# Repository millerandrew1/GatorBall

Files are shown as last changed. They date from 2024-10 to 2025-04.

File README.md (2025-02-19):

# GatorBall

# Sprint 1 10/8/2024 to 10/25/2024: Pre-Alpha Build
Work Completed: 
  This sprint we focuses on the front end of our design. We worked on showing dummy data and making the program that the referee will be using when determining the position of the football. We created a client that would act as our "football" and that would connect to a server and send dummy data which represents the distance from the anchor points. Then we have a python script called ble_triangulate.py that does the calculation of the exact position of the client and then we output that to our UI which displays the data. 

  We received our ESP-32 and DW3000 on Thursday the day before the Pre-Alpha was due so we did not have time to write a lot of code but we did have resources that we previously found and used that code to test our microchips. We were successfully able to send and receive data between the two chips and the data was the distance between the two microchips. In the future we will add the third DW3000 which will act as the football and it will take in the distance between the two microchips and then it will send that data to the ble_triangulate to calculate the position of the ball.

# Sprint 2 10/26/2024 to 11/22/2024: Prototype Design
This sprint we focued on getting the data from our tag to print to the UI. We tried to use another DW3000 to be the football but due to issues with Ardunio and there not being a compatible library we are sticking with the 1 anchor point and 1 tag for the prototype. The tag takes data from the anchor point through UWB and then is connected through bluetooth to our UI using a COM Port where we display the distance from the tag from the anchor point on the football field. We also have it continuously send data through the bluetooth so that every few miliseconds it gets new data and updates the UI. Also when the tag moves it is shown on the UI as a football moving on the field. 

Future plans for next sprint involve trying to incorporate a second anchor point so we can get a 2D position field instead of the 1D field we have now. We also need to make a PCB with the DW3000 and the ESP-32 along with including a power source. This will then need to be incorporated into a football. We also plan on transferring our python UI into a react application in order to make the project accessable for apps to be able to use it. Along with that we want to make our UI more interactable which will take in more inputs like line of scrimmage, first down line, and other various things involved in a football game (score, team names, clock time). We also have a football moving on the screen but we want to be able to visually show the line of scrimmage and the first down line.  

# Sprint 3 1/13/2025 to 1/30/2025: Alpha Build
This sprint we focused on several things in order to maximize our productivity. First we started working on the PCB that will go into the football and we are designing it on KiCad. We also ordered another anchor point to use as testing for our two anchor point postion triangulation. For our beta build if our PCB is not ready we want to use this extra anchor point as the football so we can start writing the code for it.  Next we updated our UI to be able to take in inputs and have the first down and line of scrimmage lines move depending on where the user wants the lines to be placed. We also are trying to use react to be able to host the program instead of python.

# Sprint 4 1/31/2025 to 2/21/2025: Beta Build
This sprint we continued to add features to the UI. We allowed the user to select which side of the field the line of scrimmage and first down markers were. We also made the lines scaled better and we created a formula to make the football move to scale as it would on a real field. We designed our PCB and ordered it and continued to wrok on the React application. We also designed and printed pylons for the anchor points. 

# PROCESS FOR RUNNING CODE AND CONNECTING BLUETOOTH TO PC

First go to src/hardware/range_rx and upload that Arduino code to one of the DW3000 ESP 32 modules. That is now the tag. Then in src/hardware/range_tx upload that to the other one and that is your anchor point. They should now be sending data to each other and the tag should be serial printing the distance. To connect the tag to the bluetooth go to bluetooth settings and scroll down and click devices then in there click more bluetooth settings. In there click the tab that says COM PORTS and click add and add the ESP_32. Take note of what COM Port it is connected to. Finally go to src/FrontEnd/ui.py. Change line 44 to reflect what COM port the bluetooth is transmitting through. Then, open PUTTY or any other application used to connect to serial ports. Connect to the COM port you recorded and use a baud rate of 115200. Ensure that you can see data coming in over the serial port terminal. If so, close the serial port terminal. You are now ready to run the application. Execute "python ui.py" and you should see data printing to the UI as well as the position of the ball changing on screen. To identofy we named the two anchor points the one with the short cord is 12.

# BUGS

Bluetooth and UWB, like many other wireless protocols, are finicky. Throughout our design process, we have encountered many situations where connecting to the ESP32 tag that we will be putting into a football over Bluetooth has been unreliable and difficult to get working at times. Furthermore, after testing the UWB capabilities of the DWM3000 modules, we’ve discovered that it is prone to interference from physical obstructions like walls and even people as the transmission of data is impeded by these effects. Our workaround to these issues for the purpose of the prototype has been to disconnect and reconnect to the Bluetooth device as well as maintaining “line of sight” for the two ESP32s communicating over UWB. Also, we check to ensure that the data we are receiving is of the valid format (i.e., a numerical float value). We have determined that at this time, so long as the proper preparations have been made, there is currently no need for any other error correction or recovery mechanisms for the prototype. However, in the future, we would like to implement an Automatic Repeat Request (ARQ) system for 1) the device communicating with the tag over Bluetooth and 2) the tags and anchors communicating over UWB. This will assist in ensuring that instances of data are received correctly by the relevant devices and provide us with more precision with the real-time location tracking of the football. 

# DEPENDENCIES

Bleak BLE - https://github.com/hbldh/bleak 
Localization - https://github.com/kamalshadi/Localization
Localization dependency (may not be needed) - https://shapely.readthedocs.io/en/stable/

Installation commands
pip install localization
pip install bleak
pip install shapely

# Effort Log
Please disregard the effort log in this repo because you cannot see the comments made. The link for our effort log is here at this link below:
https://docs.google.com/spreadsheets/d/1YpcHQpgFyinJQXn12217S25mA8S0SkYA/edit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

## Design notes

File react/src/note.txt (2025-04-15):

# WebSocket Imports
    @app.websocket("/ws")
    async def websocket_endpoint(websocket: WebSocket)
        await websocket.accept()
        data = {"time": curren_time, "yardX": current_ball_x, "yardY": current_ball_y}
        await websocket.send_json(data)
        await asyncio.sleep(1)

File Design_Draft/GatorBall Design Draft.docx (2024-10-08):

GatorBall Design Draft

Introduction - project value

- Purpose/Need - Describe the purpose in society for the project you are designing. Specifically, explain why it is needed, by whom, and in what context. Identify how the project is useful and goes beyond a mere demonstration.
  - This product is intended for football enthusiasts to accurately track first-downs without the need for a referee. It is needed because having a referee step out onto the field to manually measure the football and determine if a first-down has been established greatly slows down the momentum of the game and is also cumbersome to do. Our product will resolve this issue by providing an effortless way of tracking first-downs without the need for any human intervention. This product is primarily intended for small-scale football games like flag football or, potentially, intramural-level games.
- Augustus - Domain & Prior Art - Explain the field / area of the project and describe existing work in this area. Provide examples from existing commercial products, web searches, or articles appearing in the literature. All examples should be cited. Identify what features will differentiate your solution from others and why your project will make a difference.
  - Existing work similar to our product is used heavily in the NFL [1]. The NFL embeds RFID tags in player uniforms as well as the football itself. These RFID tags are extremely lightweight and unobtrusive, so they have a negligible impact on gameplay. The data collected by these tags allows the NFL to track statistics such as ball height, position, velocity, as well as player speed, passing rates and much more. These statistics greatly enhance the quality of the game and allow for the NFL as well as football enthusiasts at home to deep-dive into player stats. Our product, on the other hand, will focus specifically on the ball position to allow us to determine if a first-down has been made.
- Tyler - Impact & Risk Assessment - societal impact (culture, global, economic, environmental and social), ethical context and potential risks
  - The impacts of this product are limited to within the game of football, which is nonetheless an important institution in our local culture. By eliminating manual measurements in the game it becomes more efficient and quicker to run. This may have the effect of making the game easier to watch and therefore more popular, changing its role in our culture. By saving on the labour costs of taking these measurements, football leagues will benefit economically, although this comes at the cost of the jobs lost due to the technology. Some football fans might also consider the use of the technology inauthentic to the game; such a cultural impact to the sport itself might not be assessable without having to introduce the technology.

Joshua - Statement of Work - work to be done during semester

Milestones -

- Semester 1: Design revision (Week 8), Pre-Alpha build (Week 10/11), Design Prototype (Week 13/14), Design Prototype Presentation (Week 14/15)
- Semester 2: Alpha Build and Test Plan (Week 3), Beta Build and Test Plans, Alpha Results (Week 6), Progress Presentation (Week 7), Preliminary Report and Release Candidate (Week 10), Final Report and Production Release(Week 13), Final Presentation (Week 14/15)

Core Features-

- Microprocessor or active RFID within the football to gather and relay positional data
- Location relays using microprocessors located within/on the first down markers and pylons to provide better positional data using active RFID and Bluetooth systems
- User facing application to display data and show location of spot for the football
- Communication protocols over Bluetooth for user data transmission and RFID in order to gather positional data
- Positional data accurate to within <10 cm to ensure proper spots.
- Fast accurate triangulation of location.

Secondary Features-

- Positional data accurate to within <3 cm ideally for accurate placement and use within professional settings
- 2 anchors within each end zone to reduce costs and computation
- If using a microprocessor application within footballs, potential to gather other data such as speed, rotation and other forces the football experiences through play.
- Error detection for wireless communication

Design Revision - Improve on our product roadmap and further research and revision towards planning our project.

Pre-Alpha Build - Provide a clear foundation for the products infrastructure and architecture, research, design and experimentation on potential solutions to ensure communication between the microprocessor, location relays for collection of positional data and user devices to show the data they need.

Design Prototype - Demonstrate the core features and feasibility of our product, namely communication between microprocessor and locational relays to be able to show position of the football.

Prototype Presentation - Outline current status and future goals of the project moving into semester 2. Including a prototype demonstration and deliverable plan to complete final deliverable.

Deliverable Artifacts - what will be delivered at the end of the project? Hardware, software, and documentation

- A short description of the artifact – how does it fit into the project as a whole?
  - At the end of the project, our team will deliver a package composed of a few different artifacts. The hardware we will deliver at the end of the project will be a microprocessor that continuously collects positional data (and potentially velocity and rotational inertia) from a RFID tag. The software we will deliver will include the code we use to accomplish this. Finally, we will deliver user-friendly documentation that outlines how to set up and use the product.
- For software/documentation, dissemination plan: format and distribution of project
- Joshua | Accessibility/Usability/Maintenance Plan - how will the project remain useful long term?

Mockups - visual models; wireframes, draft schematics, and other diagrams

- Interfaces - parts of project with human interaction | Ricardo
  - Physical/Graphical Interface - The live location of the football will be displayed on a computer screen via some web based interface. On this interface, the user will be able to see a 2D representation of a football field along with the football’s current location, the line of scrimmage (highlighted red), and the first down line (highlighted yellow). Additional information such as yardage-to-gain, play clock, game clock, etc. will also be displayed on the screen.
  - Outside of displaying data, would there be any need for interaction for the following interface?^^^
  - Need to create a sketch/diagram of possible display screen
  - Programming Interface - There will be 4 Decawave 3000s present in our design: two acting as anchor points in each end zone, one within the football, and one connected to a central processing system located near half-field. These four modules will communicate via ultra wideband signals to triangulate and track the location of the football during the game. The module part of the central processing system will be connected to the PROCESSOR with SPI and relay the current location of the football. Lastly, the processor will be connected to an output device (laptop, CPU, mobile, etc.) where the data will be displayed, stored, and manipulated.
  - Still need to write specification about calls and/or protocols and diagrams
- Tyler - Systems - how systems communicate with each other (hardware and software)
- Augustus - Networking - any type of telecommunication; application
- Storyboards - mockup of each software screen | Ricardo
  - Heavily diagram/visually based
  - Mock data display screen
- Andrew - Draft Schematics - draft model for schematics; major components, what they do and how they connect

Below are pictures of the DW3000 and a nRF52 that will be located on a PCB inside the football. The DW3000 will take the information from the anchor points and send the data through SPI to the nRF52 microcontroller which will do the calculations and send data to the computer program to the referee. Pins 5-8 on the DW3000 are general I/O pins so we will use those and the same thing for the nRF52 pins P0.03 to P0.06 are general purpose I/O pins. So we will connect Pin 5 to P0.03 for MOSI, Pin 6 to P0.04 for MISO, Pin 7 to P0.05 for the SCK and Pin 8 to P0.06 for the SS. The nRF52 will control the clock and the select line and these configurations will allow us to communicate the DW3000 with the nRF52.

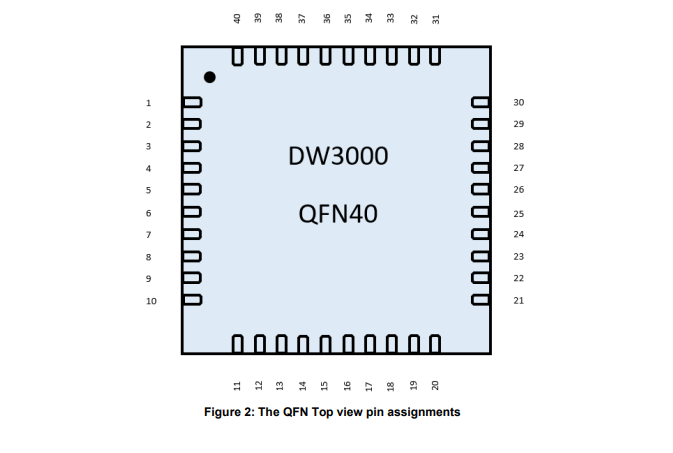
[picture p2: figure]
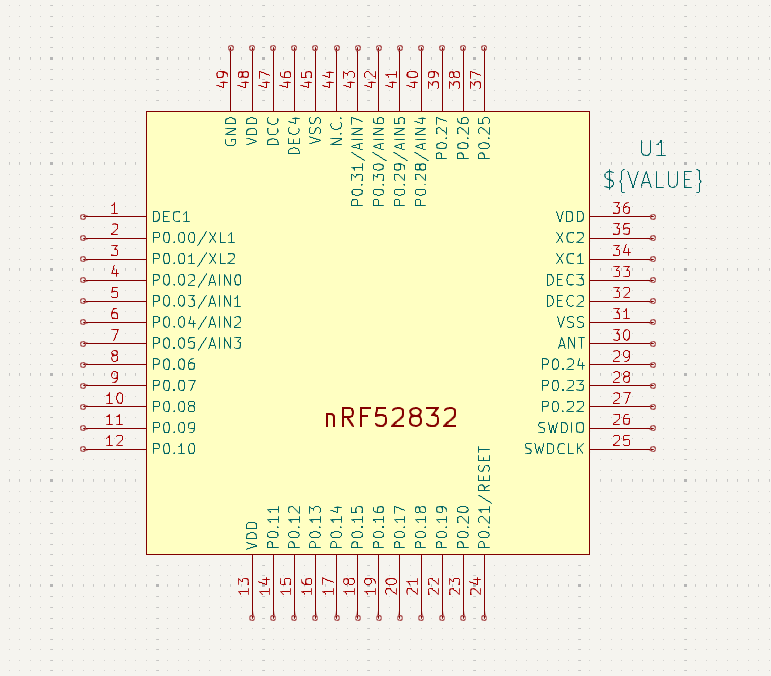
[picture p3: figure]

Sources:

[1] https://www.engineering.com/the-technology-behind-the-nfls-incredibly-precise-stats/

Final design (for now):

2x https://www.makerfabs.com/esp32-uwb-dw3000.html [anchors]

1x https://www.qorvo.com/products/p/DWM3000 [transponder], we will fit this on to a custom PCB to minimize footprint of physical component inside football since we don’t need a lot of the features from the microcontroller linked above.

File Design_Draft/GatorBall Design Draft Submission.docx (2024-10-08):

CEN3907C

7 October 2024

GatorBall Design Draft

Tyler Burndt | Andrew Miller | Ricardo Nivar-Cortes | Augustus Rodriguez | Joshua White

Introduction

Purpose / Need:

This product is intended for football enthusiasts to accurately track first-downs without the need for a referee. It is needed because having a referee step out onto the field to manually measure the football and determine if a first-down has been established greatly slows down the momentum of the game and is also cumbersome to do. Our product will resolve this issue by providing an effortless way of tracking first-downs without the need for any human intervention. This product is primarily intended for small-scale football games like flag football or, potentially, intramural-level games.

Domain & Prior Art:

Existing work similar to our product is used heavily in the NFL [1]. The NFL embeds RFID tags in player uniforms as well as the football itself. These RFID tags are extremely lightweight and unobtrusive, so they have a negligible impact on gameplay. The data collected by these tags allows the NFL to track statistics such as ball height, position, velocity, as well as player speed, passing rates and much more. These statistics greatly enhance the quality of the game and allow for the NFL as well as football enthusiasts at home to deep-dive into player stats. Our product, on the other hand, will focus specifically on the ball position to allow us to determine if a first-down has been made.

Impact & Risk Assessment:

The impacts of this product are limited to within the game of football, which is nonetheless an important institution in our local culture. By eliminating manual measurements in the game it becomes more efficient and quicker to run. This may have the effect of making the game easier to watch and therefore more popular, changing its role in our culture. By saving on the labor costs of taking these measurements, football leagues will benefit economically, although this comes at the cost of the jobs lost due to the technology. Some football fans might also consider the use of the technology inauthentic to the game; such a cultural impact to the sport itself might not be assessable without having to introduce the technology.

Statement of Work:

Milestones -

- Semester 1: Design revision (Week 8), Pre-Alpha build (Week 10/11), Design Prototype (Week 13/14), Design Prototype Presentation (Week 14/15)

Core Features-

- Ultra-wideband (DWM 3000) controlled with a microprocessor (ESP32-C3) within the football to gather and relay positional data to anchors
- Anchors within each end-zone to triangulate position of the football using UWB with microprocessor controller (ATXmega)
- User facing application to display data and show location of spot for the football
- Communication protocols over Bluetooth for user data transmission and UWB in order to gather positional data
- Positional data accurate to within <10 cm to ensure proper spots.
- Fast accurate triangulation of location.

Secondary Features-

- Positional data accurate to within <3 cm ideally for accurate placement and use within professional settings
- 2 anchors within each end zone to reduce costs and computation
- Error detection for wireless communication

Performance Specifications -

- Operation Voltage - 3.3V for all microprocessors and DWM
- Power Consumption - 250mW for DWMs, 80mW for ESP32-C3, 100mW for ATXmegas
- Bandwidth - 850kbps-6.8Mbps for DWM
- Connectivity- SPI Communication between microcontroller and DWMs, UWB for communication between anchors and ball. Bluetooth connection to main computer running computation.
- Languages and Software - C/C++ for running microcontrollers and on the main computer. JS/HTML/CSS for web application.

Milestone Goals for Semester 1 -

- Design Revision - Improve on our product roadmap and further research and revision towards planning our project.
- Pre-Alpha Build - Provide a clear foundation for the products infrastructure and architecture, research, design and experimentation on potential solutions to ensure communication between the microprocessor, location relays for collection of positional data and user devices to show the data they need. Have basic operations for triangulation done.
- Design Prototype - Demonstrate the core features and feasibility of our product, namely UWB communication between the football and locational relays to be able to show position and display data.
- Prototype Presentation - Outline current status and future goals of the project moving into semester 2. Including a prototype demonstration and deliverable plan to complete final deliverable.

Deliverable Artifacts:

At the end of the project, our team will deliver a package composed of a few different artifacts. The hardware we will deliver at the end of the project will be a microprocessor that continuously collects positional data (and potentially velocity and rotational inertia) from a transponder (DW3000 module). The software we will deliver will include the code we use to accomplish this as well as user-friendly documentation that outlines how to set up and use the product.

For software/documentation, dissemination plan: format and distribution of project

Our project is planned to be implemented in fields and stadiums by us and the data gathered would be sent to referees to be used during games and testing. The footballs will also be modified by us by placing the PCB generated to enable UWB communication inside, with the microcontroller programmed to communicate. To ensure proper function of the systems, referees can test the position by placing a football at different locations on the field and verifying through software that the position is correct. For maintenance, each field/stadium will have multiple balls, depending on the level of play it could be 10-100+ balls, and if one breaks or has issues they can be replaced before the game is affected. These balls then could be sent back to be repaired if damages aren’t too heavy.

Mockups

Interfaces/Systems/Networking:

Physical/Graphical Interface - The live location of the football will be displayed on a computer screen via a web based interface. On this interface, the user will be able to see a 2D representation of a football field along with the football’s current location, the line of scrimmage (highlighted red), and the first down line (highlighted yellow). Additional information such as yardage-to-gain, play clock, game clock, etc. will also be displayed on the screen. (This display screen is located in the storyboards section)

Programming Interface - There will be 3 DWM3000 modules present in our design: two acting as anchor points in each end zone and one within the football. These three modules will communicate via ultra wideband signals to triangulate and track the location of the football during the game. The two modules acting as anchor points will have ATXMega controllers to control the signal inputs/outputs via SPI. The module that’s located in the football will be connected to the ESP32 via SPI and track the current position of the football. Lastly, the processor will be connected to an output device (laptop, CPU, mobile, etc.) via Bluetooth (BLE) where the data will be displayed, stored, and manipulated.

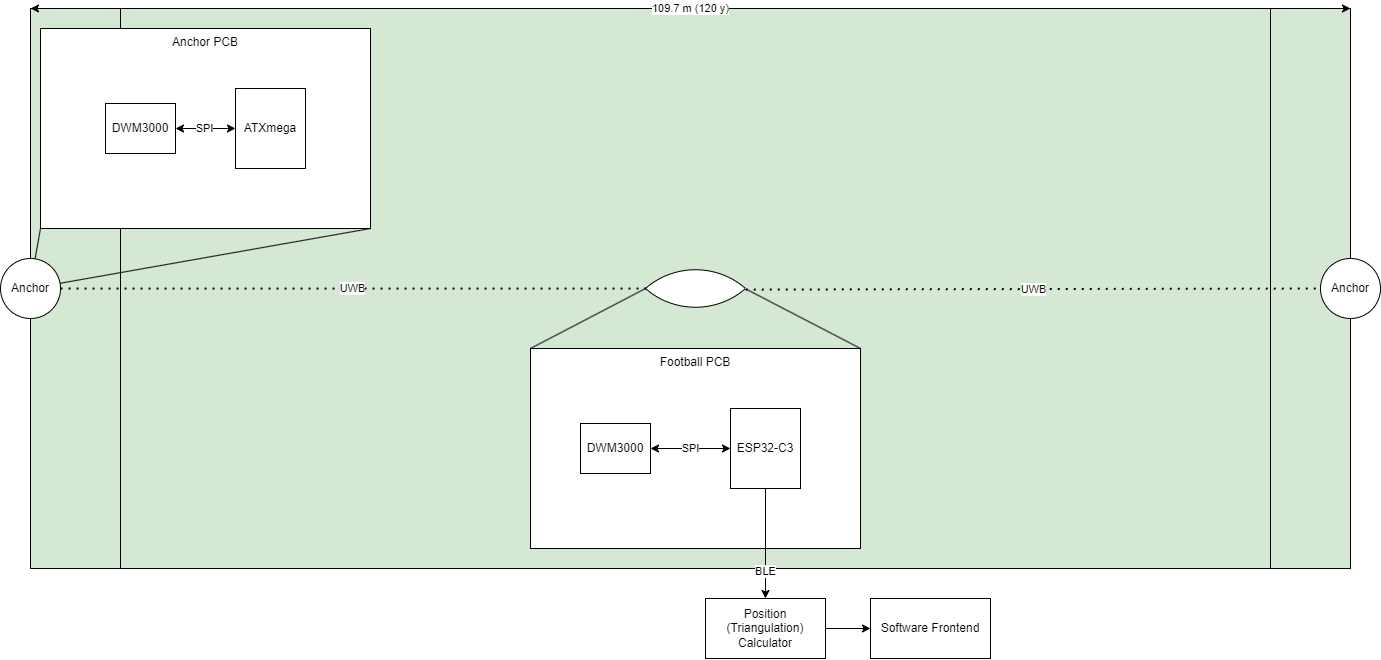
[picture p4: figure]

Storyboards:

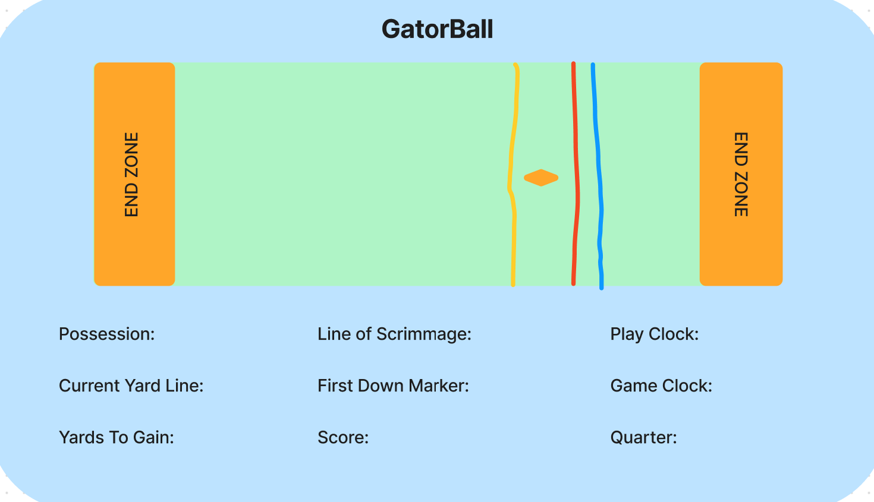
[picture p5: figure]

The image above is the screen on which our data would be displayed. The location of the football is represented by the horizontal diamond and will update live throughout the course of the game. Referees will also be able to view information pertaining to the game itself through this screen. The different colored lines located on the football field are representative of different markers: the yellow line is the first down marker, the red line is the line of scrimmage, and the blue line is the current down marker.

Draft Schematics:

Below is how we will connect the DW3000 and ESP-32 in order to use SPI to communicate between the two chips inside the football. The DW3000 will take the information from the anchor points and send the data through SPI to the ESP_32 microcontroller which will do the calculations and send data to the computer program to the referee. We will use general I/O pins on the DW3000 to connect to the SPI of the ESP32. We will connect the SPID to GPIO3 for the MOSI, SPIQ to GPIO2 for MISO, GPIO1 to SPICLK for the SCK, and GPIO0 to SPICS0 for SS.

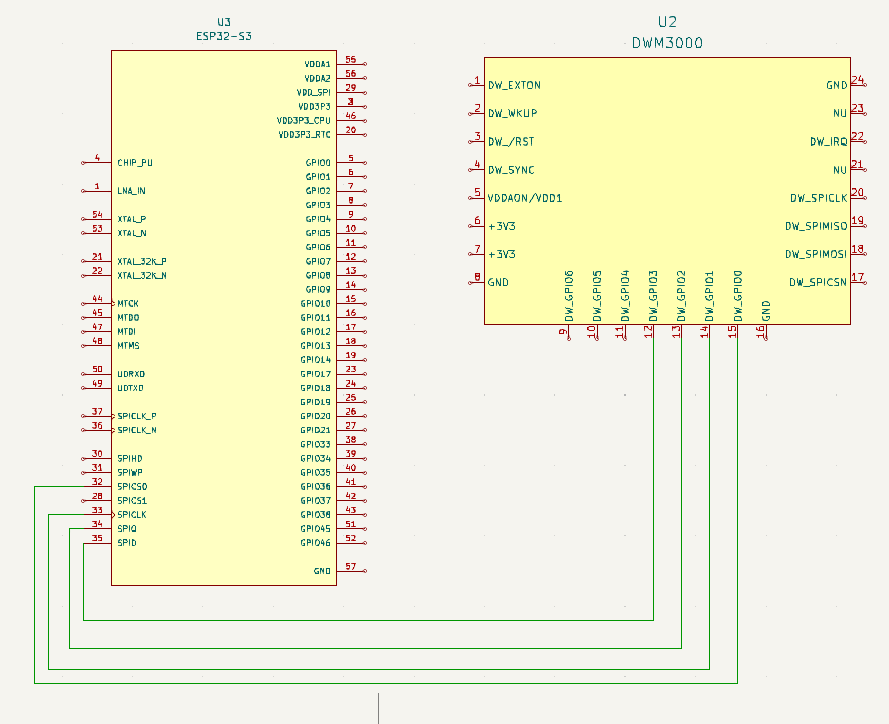
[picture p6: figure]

For the anchor points we will be using the ATxmega128A1U as the microchip to connect to the DW3000. We will use the same pins for the DW3000 as used above but for the ATxmega we will use pins corresponding to PORTC as it has SPI capability. For PORTC we will make PC3 for MOSI, PC2 for MISO, PC1 for SCK, and PC0 for the SS. Below is how we will wire the DW3000 to the ATxmega.

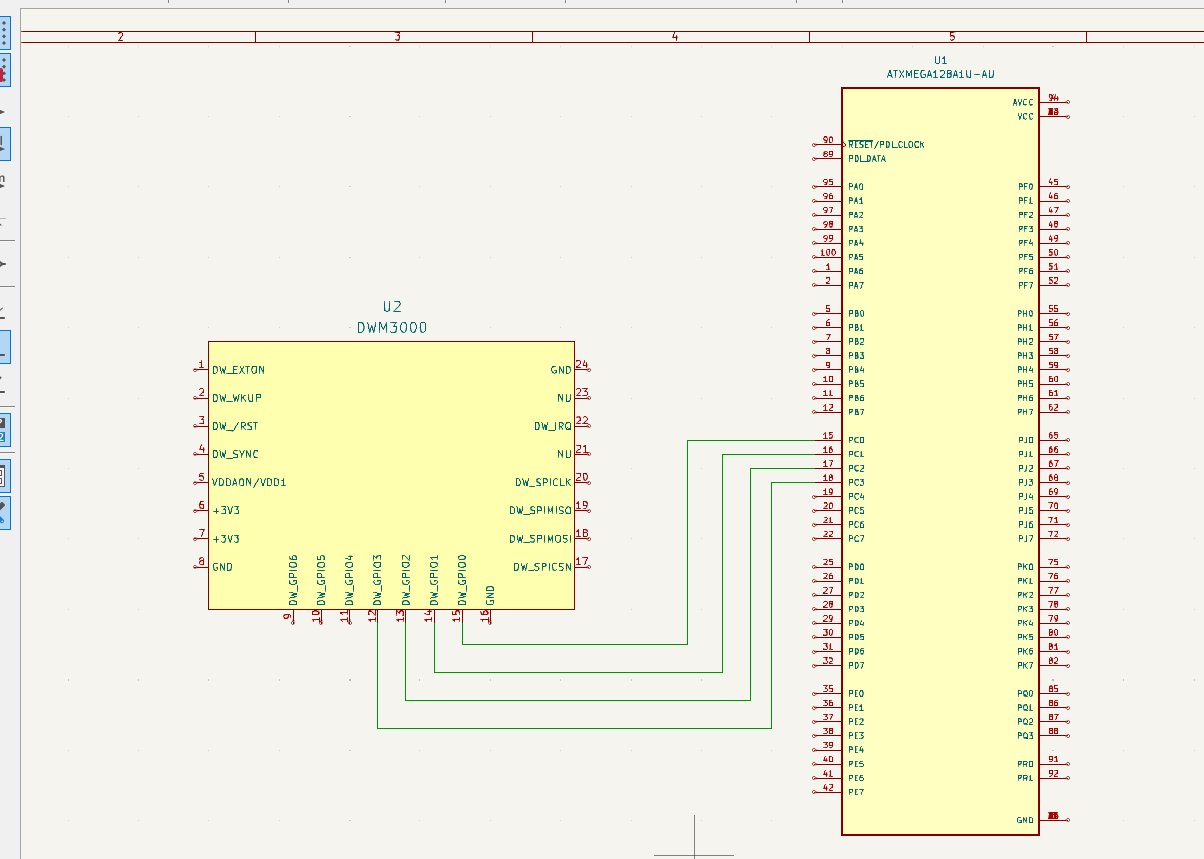
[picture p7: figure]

Sources:

[1] https://www.engineering.com/the-technology-behind-the-nfls-incredibly-precise-stats/

Final design (for now):

https://www.makerfabs.com/esp32-uwb-dw3000.html | anchors

https://www.qorvo.com/products/p/DWM3000 | transponder; we will fit this on to a custom PCB to minimize the footprint of the physical component inside the football since we don’t need a lot of the features from the microcontroller linked above.

https://www.espressif.com/sites/default/files/documentation/esp32_datasheet_en.pdf | ESP-32 datasheet

https://ww1.microchip.com/downloads/en/DeviceDoc/atmel-8385-8-and-16-bit-avr-microcontroller-atxmega64a1u-atxmega128a1u_datasheet.pdf | ATxmeaga128 datasheet

https://www.qorvo.com/products/p/DW3110#documents | DW3000 Documents

https://www.figma.com/board/rOKxpPEDzPgp7Nbc284U8L/GatorBall-Display-Screen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 | Storyboard (Display Screen)

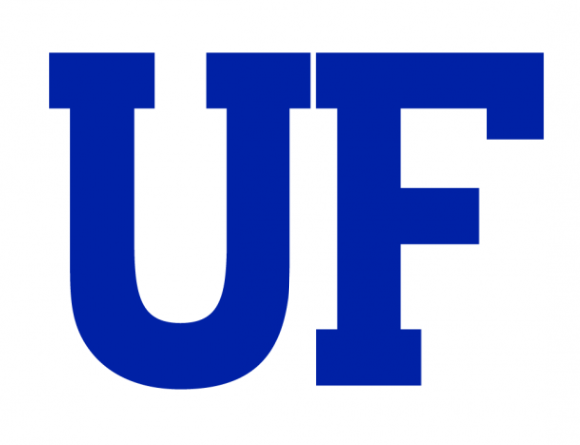
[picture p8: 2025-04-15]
react/src/assets/uf.png

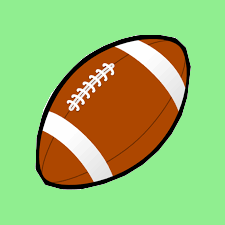
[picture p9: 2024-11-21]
react/src/football.png

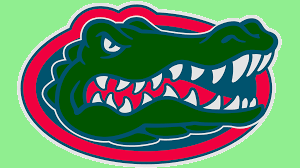
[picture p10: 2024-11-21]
react/src/gator.png

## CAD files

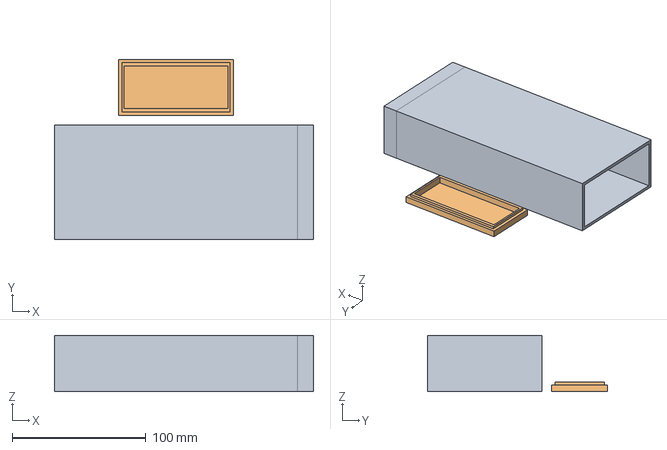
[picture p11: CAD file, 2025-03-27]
SchmaticFile/pylon_w_power.FCStd
194.0 x 135.1 x 42.0 mm

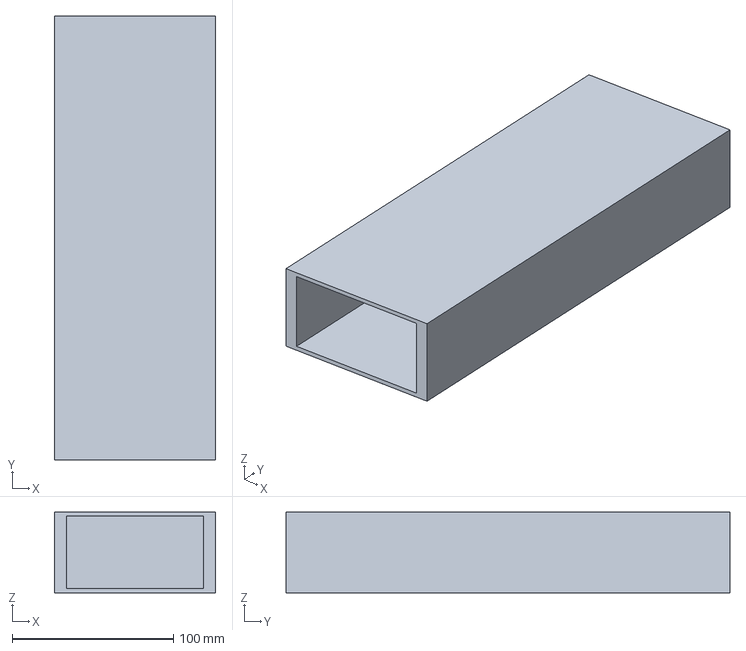
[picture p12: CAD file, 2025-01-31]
SchmaticFile/basic_pylon.FCStd
100.0 x 275.0 x 50.0 mm

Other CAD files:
SchmaticFile/football.blend
SchmaticFile/pylon_w_power.stl

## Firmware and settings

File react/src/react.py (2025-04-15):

import tkinter as tk
from threading import Thread
import queue
import serial
from PIL import Image, ImageTk
from tkinter import messagebox  
import math
import time
import traceback
import sys
import csv
import time
from datetime import datetime

# WebSocket Imports
import asyncio
import nest_asyncio
import uvicorn 
import threading
from threading import Lock
from fastapi import FastAPI, WebSocket
import json
from pathlib import Path


# Create a queue to safely pass data between threads
q = queue.Queue()

global distance
distance = 0

global started
started = False

global scrim_is_left
global fdm_is_left

global ytg_scrim_val
global ytg_fdm_val

global current_ball_x
global current_ball_y
current_ball_x = 0
current_ball_y = 0

# WebSocket Imports
global current_time
current_time = 0
app = FastAPI()
clients = set()

file = Path("gameStates.json")

if not file.exists():
    file.write_text("[]")

file_lock = Lock()

@app.websocket("/ws")
async def websocket_endpoint(websocket: WebSocket):
    await websocket.accept()
    clients.add(websocket)
    try: 
        while True:
            data = {"time": current_time, "yardX": current_ball_x, "yardY": current_ball_y}
            await websocket.send_json(data)
            await asyncio.sleep(0.1)
            try:
                with file_lock:
                    # Read current content of the file
                    with file.open("r") as f:
                        try:
                            existing_data = json.load(f)
                            if not isinstance(existing_data, list):
                                existing_data = []  # Reset if the file content is not a list
                        except json.JSONDecodeError:
                            existing_data = []  # If JSON is corrupted, reset it

                    # Append new data to the list
                    existing_data.append(data)

                    # Write the updated data back to the file
                    with file.open("w") as f:
                        json.dump(existing_data, f, indent=2)

            except Exception as e:
                print(f"Error writing to JSON file: {e}")
    except Exception as e:
        print(f"WebSocket error: {e}")
    finally:
        clients.discard(websocket)

def start_websocket_server():
    nest_asyncio.apply()
    uvicorn.run(app, host="0.0.0.0", port=8000)
# WebSocket Imports ^^^

global position_history
position_history = []

def main():
    def update_values_from_serial():
        """Update values dynamically from the queue."""
        while not q.empty():
            try:
                global distance
                global started
                global current_ball_x
                global current_ball_y

                ball_x, ball_y = q.get_nowait()

                ball_x *= 1.093
                ball_y *= 1.093

                print(f"DISPLAY X={ball_x}, DISPLAY Y={ball_y}")

                current_ball_x = ball_x
                current_ball_y = ball_y
                now = datetime.now()
                current_time = time.strftime("%H:%M:%S") + f".{now.microsecond // 1000:03d}"
                print(f"current_time: {current_time}")

                position_history.append((current_ball_x, current_ball_y, current_time))
                if len(position_history) > 50:
                    position_history.pop(0)

                yd_line = f"{ball_x:.3f} yards"

                # Example updates
                if not started:
                    started = True
                    possession.set("Team A")
                    line_of_scrimmage.set("50")
                    first_down_marker.set("25")
                    yards_to_gain.set("10 yards")
                    score.set("Home: 14 - Away: 7")
                    play_clock.set("25")
                    game_clock.set("12:00")
                    quarter.set("2nd")

                ball_pos.set(yd_line)

            except Exception as e:
                print(f"Error updating values: {e}")

        root.after(100, update_values_from_serial) 

    # ESP32 -> COM5
    # ESP3212 -> COM6
    def read_in_serial(): 
        
        """Read data from the serial port in a background thread."""
        try:
            ser1 = serial.Serial('COM3', 115200)  # CHANGE COM PORT as needed
            ser2 = serial.Serial('COM4', 115200)
            ser1.timeout = 3
            ser2.timeout = 3
            print('Serial port opened')

            def try_parse_float(s: str):
                # Replace null bytes and strip whitespace
                s_clean = s.replace('\x00', '').strip()
                # If empty after cleaning, return None
                if not s_clean:
                    return None
                try:
                    return float(s_clean)
                except ValueError:
                    return None

            # NOTE: CHANGE ANCHOR COORDINATES BEFORE USE IF NEEDED
            a_x = 0
            a_y = 0
            b_x = 0 
            b_y = 15 # ANCHOR B POSITION

            anchor1_buf = []
            anchor2_buf = []

            # Create lists to compute a moving average of the inputs
            ROLLING_SIZE = 1
            rolling_a = []
            rolling_c = []

            while True:
                now = time.monotonic()

                # Read from anchor 1 (ser1) if data available
                if ser1.in_waiting > 0:
                    raw_a = ser1.readline().decode('utf-8').strip()
                    a = try_parse_float(raw_a)
                    if a is not None:
                        anchor1_buf.append((now, a))  
                        print(f"A: {a:.3f} at {now:.3f}")

                # Read from anchor 1 (ser2) if data available
                if ser2.in_waiting > 0:
                    raw_c = ser2.readline().decode('utf-8').strip()
                    c = try_parse_float(raw_c)
                    if c is not None:
                        anchor2_buf.append((now, c))  
                        print(f"C: {c:.3f} at {now:.3f}")

                # Try to sync the most recent value of anchor1 with the most relevant anchor 2 value
                if anchor1_buf and anchor2_buf:
                    t1, a_val = anchor1_buf[-1]

                    best_idx = None
                    best_dt = float('inf')
                    best_c = None

                    for i, (t2, c_val) in enumerate(anchor2_buf):
                        dt = abs(t2 - t1)
                        if dt < best_dt:
                            best_dt = dt
                            best_idx = i
                            best_c = c_val

                    if best_idx is not None and best_dt < 0.2:  # max 200ms mismatch allowed
                        print(f"SYNCED: a={a_val}, c={best_c}, dt={best_dt:.3f}")

                        # Smooth the values (moving average)
                        rolling_a.append(a_val)
                        rolling_c.append(best_c)
                        if len(rolling_a) > ROLLING_SIZE:
                            rolling_a.pop(0)
                        if len(rolling_c) > ROLLING_SIZE:
                            rolling_c.pop(0)

                        a_avg = sum(rolling_a) / len(rolling_a)
                        c_avg = sum(rolling_c) / len(rolling_c)

                        # Compute the angle
                        try:
                            numerator = a_avg*a_avg + b_y*b_y - c_avg*c_avg
                            denominator = 2 * a_avg * b_y
                            ang_theta_val = numerator / denominator
                            ang_theta_val = max(-1, min(1, ang_theta_val))  # clamp

                            ang_theta = math.acos(ang_theta_val)
                            print(f"ANG_THETA: {ang_theta}")
                            # SWAPPED X AND Y FOR NEW ANCHOR ORIENTATION: FIXME
                            new_dist_y = a_avg * math.cos(ang_theta)
                            new_dist_x = a_avg * math.sin(ang_theta)

                            print(f"CALCULATED X={new_dist_x:.3f}, CALCULATED Y={new_dist_y:.3f}")
                            q.put((new_dist_x, new_dist_y))
                        except Exception as e:
                            print(f"Math error: {e}")

                        # Cleanup used data
                        pop1 = anchor1_buf.pop()  # last one used
                        pop2 = anchor2_buf = anchor2_buf[best_idx + 1:]  # drop old ones
                        print(f"POPPED {pop1} AND {pop2}")
        except Exception as e:
            tb = sys.exc_info()[2]
            lineno = tb.tb_lineno
            print(f"Error reading serial: {e} on line {lineno}")

    def update_screen():
        # global distance
        global current_ball_x
        global current_ball_y
        
        # ----------------------------------------------------------
        # 1) Load and resize the football image, convert to RGBA
        # ----------------------------------------------------------
        ball_img = Image.open("football.png")
        ball_img = ball_img.resize((30, 30))
        ball_img = ball_img.convert("RGBA")

        # ----------------------------------------------------------
        # 2) Remove the "lightgreen" background (#90EE90) -> (144,238,144)
        # ----------------------------------------------------------
        datas = ball_img.getdata()
        new_data = []
        for item in datas:
            # item is (R, G, B, A)
            if item[0] == 144 and item[1] == 238 and item[2] == 144:
                # Make this pixel fully transparent
                new_data.append((255, 255, 255, 0))
            else:
                new_data.append(item)
        ball_img.putdata(new_data)

        # Convert to PhotoImage for tkinter

        tk_ball_img = ImageTk.PhotoImage(ball_img)

        # Clear old football
        canvas.delete("ball")

        # x_coord = (current_ball_x + 110) * 4.5
        x_coord = (current_ball_x + 50) * 10
        y_coord = 150 - (current_ball_y * 4.5) #FIXME

        canvas.create_image(x_coord, y_coord, image=tk_ball_img,
                            anchor=tk.CENTER, tags="ball") 
        
        # Keep a reference to avoid garbage collection
        canvas.tk_ball_img_ref = tk_ball_img

        root.after(50, update_screen)

    # ----------------------------------------------------------------
    # Helper functions
    # ----------------------------------------------------------------
    def enable_edit():
        entry_possession.config(state="normal")
        entry_line_of_scrimmage.config(state="normal")
        entry_first_down_marker.config(state="normal")
        entry_yards_to_gain.config(state="normal")
        entry_score.config(state="normal")

    def save_edit():
        entry_possession.config(state="disabled")
        entry_line_of_scrimmage.config(state="disabled")
        entry_first_down_marker.config(state="disabled")
        entry_yards_to_gain.config(state="disabled")
        entry_score.config(state="disabled")

        # Validate the blue line (line_of_scrimmage)
        scrim_raw = line_of_scrimmage.get()
        try:
            yard_scrim_val = int(scrim_raw)
        except ValueError:
            messagebox.showerror(
                "Invalid Input",
                "Please enter an integer between 0 and 50 for the line of scrimmage."
            )
            return
        if yard_scrim_val < 0 or yard_scrim_val > 50:
            messagebox.showerror(
                "Invalid Input",
                "Please enter a number from 0 to 50 for the line of scrimmage."
            )
            return

        # Validate the red line (first_down_marker)
        marker_raw = first_down_marker.get()
        try:
            yard_fdm_val = int(marker_raw)
        except ValueError:
            messagebox.showerror(
                "Invalid Input",
                "Please enter an integer between 0 and 50 for the first down marker."
            )
            return
        if yard_fdm_val < 0 or yard_fdm_val > 50:
            messagebox.showerror(
                "Invalid Input",
                "Please enter a number from 0 to 50 for the first down marker."
            )
            return

        # EDGE CASE: 
        # LEFT LEFT -> normal
        # RIGHT LEFT/LEFT RIGHT -> SUBRACT 50 FROM BOTH THEN SUM
        global ytg_scrim_val
        global ytg_fdm_val
        global scrim_is_left
        global fdm_is_left

        if (scrim_is_left and fdm_is_left) or (not scrim_is_left and not fdm_is_left): # both left or both right
            yards_to_gain_val = abs(yard_scrim_val - yard_fdm_val)
        else:
            yards_to_gain_val = abs(ytg_scrim_val + ytg_fdm_val)

        yards_to_gain.set(f"{yards_to_gain_val}")
        

    def update_scrim(yard_val):
        PIXELS_PER_YARD = 5.6
        LEFT_OFFSET = 70
        RIGHT_OFFSET = 630

        global ytg_scrim_val
        ytg_scrim_val = abs(50 - yard_val)

        if endzone_side == "left":
            new_x = LEFT_OFFSET + (yard_val * PIXELS_PER_YARD)
        else: # right offset
            new_x = RIGHT_OFFSET - (yard_val * PIXELS_PER_YARD)

        canvas.coords(scrimmage_line_id, new_x, 0, new_x, 250)
        print(f"Blue line updated to yard {yard_val} at x={new_x}")

    def update_first_down(yard_val):
        PIXELS_PER_YARD = 5.6
        LEFT_OFFSET = 70
        RIGHT_OFFSET = 630

        global ytg_fdm_val
        ytg_fdm_val = abs(50 - yard_val)

        if endzone_side == "left":
            new_x = LEFT_OFFSET + (yard_val * PIXELS_PER_YARD)
        else: # right offset
            new_x = RIGHT_OFFSET - (yard_val * PIXELS_PER_YARD)

        canvas.coords(first_down_line_id, new_x, 0, new_x, 250)
        print(f"Red line updated to yard {yard_val} at x={new_x}")

    def set_left_scrim():
        nonlocal endzone_side
        endzone_side = "left"

        global scrim_is_left
        scrim_is_left = True

        try:
            scrim_val = int(line_of_scrimmage.get())
            # marker_val = int(first_down_marker.get())
        except ValueError:
            messagebox.showerror(
                "Invalid Input",
                "Please enter an integer from 0 to 50 for the line of scrimmage."
            )
            return  # If invalid, just ignore
        if (scrim_val < 0) or (scrim_val > 50):
            messagebox.showerror(
                "Invalid Input",
                "Please enter a number from 0 to 50 for the line of scrimmage."
            )
            return
        
        update_scrim(scrim_val)

    def set_right_scrim():
        nonlocal endzone_side
        endzone_side = "right"

        global scrim_is_left 
        scrim_is_left = False

        try:
            scrim_val = int(line_of_scrimmage.get())
            # marker_val = int(first_down_marker.get())
        except ValueError:
            messagebox.showerror(
                "Invalid Input",
                "Please enter an integer from 0 to 50 for the line of scrimmage."
            )
            return  # If invalid, just ignore
        if (scrim_val < 0) or (scrim_val > 50):
            messagebox.showerror(
                "Invalid Input",
                "Please enter a number from 0 to 50 for the line of scrimmage."
            )
            return

        update_scrim(scrim_val)

    def set_left_fdm():
        nonlocal endzone_side
        endzone_side = "left"

        global fdm_is_left
        fdm_is_left = True

        try:
            # scrim_val = int(line_of_scrimmage.get())
            marker_val = int(first_down_marker.get())
        except ValueError:
            messagebox.showerror(
                "Invalid Input",
                "Please enter an integer from 0 to 50 for the first down marker."
            )
            return  # If invalid, just ignore
        if (marker_val < 0) or (marker_val > 50):
            messagebox.showerror(
                "Invalid Input",
                "Please enter an integer from 0 to 50 for the first down marker."
            )
            return

        update_first_down(marker_val)

    def set_right_fdm():
        nonlocal endzone_side
        endzone_side = "right"

        global fdm_is_left
        fdm_is_left = False
        
        try:
            # scrim_val = int(line_of_scrimmage.get())
            marker_val = int(first_down_marker.get())
        except ValueError:
            messagebox.showerror(
                "Invalid Input",
                "Please enter an integer from 0 to 50 for the first down marker."
            )
            return  # If invalid, just ignore
        if (marker_val < 0) or (marker_val > 50):
            messagebox.showerror(
                "Invalid Input",
                "Please enter an integer from 0 to 50 for the first down marker."
            )
            return

        update_first_down(marker_val)

    """Check if input_string can be converted to a float"""
    def is_float(input_string):
        try:
            float(input_string)
            return True
        except ValueError:
            return False
        
    def export_history():
        global position_history
        filename = "position_log.csv"
        try:
            with open(filename, "w", newline="") as f:
                writer = csv.writer(f)
                # Write a header row
                writer.writerow(["Timestamp", "X (yards)", "Y (yards)"])
                # Write each position
                for (px, py, tstamp) in position_history:
                    writer.writerow([tstamp, f"{px:.3f}", f"{py:.3f}"])
            messagebox.showinfo("Export complete", f"History exported to {filename}")
        except Exception as e:
            messagebox.showerror("Export error", f"Could not export CSV: {e}")

    # ----------------------------------
    # Main GUI setup
    # ----------------------------------
    root = tk.Tk()
    root.title("GatorBall")
    root.geometry("900x580")
    root.configure(bg="lightblue")

    canvas = tk.Canvas(root, width=700, height=250, bg="lightgreen", highlightthickness=0)
    canvas.place(x=50, y=50)

    endzone_side = "left" # Default to left

    update_screen()

    # Gator image
    gator = Image.open("gator.png")
    gator = gator.resize((200, 150))
    gator = ImageTk.PhotoImage(gator)
    canvas.create_image(350, 120, image=gator, anchor=tk.CENTER, tags="gator")

    # End zones
    canvas.create_rectangle(0, 0, 70, 250, fill="orange")
    canvas.create_rectangle(630, 0, 700, 250, fill="orange")
    canvas.create_text(35, 125, text="END ZONE", angle=90, font=("Helvetica", 8), fill="black")
    canvas.create_text(665, 125, text="END ZONE", angle=90, font=("Helvetica", 8), fill="black")

    # Red line
    first_down_line_id = canvas.create_line(575, 0, 575, 250, fill="red", width=3)

    # Blue line
    scrimmage_line_id = canvas.create_line(530, 0, 530, 250, fill="blue", width=3)

    # StringVars
    possession = tk.StringVar()
    line_of_scrimmage = tk.StringVar()
    first_down_marker = tk.StringVar()
    yards_to_gain = tk.StringVar()
    score = tk.StringVar()
    play_clock = tk.StringVar()
    game_clock = tk.StringVar()
    quarter = tk.StringVar()
    ball_pos = tk.StringVar()
    ball_x_new = tk.StringVar()

    # Initial
    possession.set("N/A")
    line_of_scrimmage.set("N/A")
    first_down_marker.set("N/A")
    yards_to_gain.set("N/A")
    score.set("N/A")
    play_clock.set("N/A")
    game_clock.set("N/A")
    quarter.set("N/A")
    ball_pos.set("N/A")

    # Labels/entries
    label_possession = tk.Label(root, text="Possession:", font=("Helvetica", 12), bg="lightblue")
    label_possession.place(x=50, y=350)
    entry_possession = tk.Entry(root, textvariable=possession, font=("Helvetica", 12), state="disabled")
    entry_possession.place(x=250, y=350)

    label_line_of_scrimmage = tk.Label(root, text="Line of Scrimmage:", font=("Helvetica", 12), bg="lightblue")
    label_line_of_scrimmage.place(x=50, y=410)
    entry_line_of_scrimmage = tk.Entry(root, textvariable=line_of_scrimmage, font=("Helvetica", 12), state="disabled")
    entry_line_of_scrimmage.place(x=250, y=410)

    label_distance_anchor = tk.Label(root, text="Distance from anchor point:", font=("Helvetica", 12), bg="lightblue")
    label_distance_anchor.place(x=50, y=380)
    entry_ball_pos = tk.Entry(root, textvariable=ball_pos, font=("Helvetica", 12), state="disabled")
    entry_ball_pos.place(x=250, y=380)

    label_first_down_marker = tk.Label(root, text="First Down Marker:", font=("Helvetica", 12), bg="lightblue")
    label_first_down_marker.place(x=450, y=410)
    entry_first_down_marker = tk.Entry(root, textvariable=first_down_marker, font=("Helvetica", 12), state="disabled")
    entry_first_down_marker.place(x=600, y=410)

    label_yards_to_gain = tk.Label(root, text="Yards To Gain:", font=("Helvetica", 12), bg="lightblue")
    label_yards_to_gain.place(x=450, y=380)
    entry_yards_to_gain = tk.Entry(root, textvariable=yards_to_gain, font=("Helvetica", 12), state="disabled")
    entry_yards_to_gain.place(x=600, y=380)

    label_score = tk.Label(root, text="Score:", font=("Helvetica", 12), bg="lightblue")
    label_score.place(x=450, y=350)
    entry_score = tk.Entry(root, textvariable=score, font=("Helvetica", 12), state="disabled")
    entry_score.place(x=600, y=350)

    # Buttons
    edit_button = tk.Button(root, text="Edit", command=enable_edit, font=("Helvetica", 20))
    edit_button.place(x=370, y=500)

    save_button = tk.Button(root, text="Save", command=save_edit, font=("Helvetica", 20))
    save_button.place(x=470, y=500)

    left_button_scrim = tk.Button(root, text="Left", command=set_left_scrim, font=("Helvetica", 14))
    left_button_scrim.place(x=290, y=440)

    right_button_scrim = tk.Button(root, text="Right", command=set_right_scrim, font=("Helvetica", 14))
    right_button_scrim.place(x=350, y=440)
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

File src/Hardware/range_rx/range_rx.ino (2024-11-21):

#include "dw3000.h"
#include "BluetoothSerial.h"
BluetoothSerial SerialBT;
BluetoothSerial btSerial;


#define PIN_RST 27
#define PIN_IRQ 34
#define PIN_SS 4

#define RNG_DELAY_MS 100
#define TX_ANT_DLY 16385
#define RX_ANT_DLY 16385
#define ALL_MSG_COMMON_LEN 10
#define ALL_MSG_SN_IDX 2
#define RESP_MSG_POLL_RX_TS_IDX 10
#define RESP_MSG_RESP_TX_TS_IDX 14
#define RESP_MSG_TS_LEN 4
#define POLL_TX_TO_RESP_RX_DLY_UUS 240
#define RESP_RX_TIMEOUT_UUS 400

/* Default communication configuration. We use default non-STS DW mode. */
static dwt_config_t config = {
    5,                /* Channel number. */
    DWT_PLEN_128,     /* Preamble length. Used in TX only. */
    DWT_PAC8,         /* Preamble acquisition chunk size. Used in RX only. */
    9,                /* TX preamble code. Used in TX only. */
    9,                /* RX preamble code. Used in RX only. */
    1,                /* 0 to use standard 8 symbol SFD, 1 to use non-standard 8 symbol, 2 for non-standard 16 symbol SFD and 3 for 4z 8 symbol SDF type */
    DWT_BR_6M8,       /* Data rate. */
    DWT_PHRMODE_STD,  /* PHY header mode. */
    DWT_PHRRATE_STD,  /* PHY header rate. */
    (129 + 8 - 8),    /* SFD timeout (preamble length + 1 + SFD length - PAC size). Used in RX only. */
    DWT_STS_MODE_OFF, /* STS disabled */
    DWT_STS_LEN_64,   /* STS length see allowed values in Enum dwt_sts_lengths_e */
    DWT_PDOA_M0       /* PDOA mode off */
};

static uint8_t tx_poll_msg[] = {0x41, 0x88, 0, 0xCA, 0xDE, 'W', 'A', 'V', 'E', 0xE0, 0, 0};
static uint8_t rx_resp_msg[] = {0x41, 0x88, 0, 0xCA, 0xDE, 'V', 'E', 'W', 'A', 0xE1, 0, 0, 0, 0, 0, 0, 0, 0, 0, 0};
static uint8_t frame_seq_nb = 0;
static uint8_t rx_buffer[20];
static uint32_t status_reg = 0;
static double tof;
static double distance;
extern dwt_txconfig_t txconfig_options;


void macStringToBytes(const char* macStr, uint8_t* macBytes) {
    sscanf(macStr, "%hhx:%hhx:%hhx:%hhx:%hhx:%hhx",
           &macBytes[0], &macBytes[1], &macBytes[2], 
           &macBytes[3], &macBytes[4], &macBytes[5]);
}


void multiSend(char * buffer, int size) {
  for (int i = 0; i < size; i++) {
    btSerial.write(buffer[i]);
  }
}

void setup()
{
  const char* serverAddress = "C0:3C:59:65:AA:E9"; 
  const int serverChannel = 4; 
  Serial.begin(115200);
  SerialBT.begin("ESP32_Distance");  // Name of the ESP32 Bluetooth device
  Serial.println("Bluetooth initialized.");

  uint8_t serverAddressBytes[6];
    macStringToBytes(serverAddress, serverAddressBytes);

    // Attempt to connect to the server
    if (SerialBT.connect(serverAddressBytes, serverChannel)) {
        Serial.println("Connected to Bluetooth server!");
      
    } else {
        Serial.println("Failed to connect to Bluetooth server.");
    }

  UART_init();

  spiBegin(PIN_IRQ, PIN_RST);
  spiSelect(PIN_SS);

  delay(2); // Time needed for DW3000 to start up (transition from INIT_RC to IDLE_RC, or could wait for SPIRDY event)

  while (!dwt_checkidlerc()) // Need to make sure DW IC is in IDLE_RC before proceeding
  {
    UART_puts("IDLE FAILED\r\n");
    while (1)
      ;
  }

  if (dwt_initialise(DWT_DW_INIT) == DWT_ERROR)
  {
    UART_puts("INIT FAILED\r\n");
    while (1)
      ;
  }

  // Enabling LEDs here for debug so that for each TX the D1 LED will flash on DW3000 red eval-shield boards.
  dwt_setleds(DWT_LEDS_ENABLE | DWT_LEDS_INIT_BLINK);

  /* Configure DW IC. See NOTE 6 below. */
  if (dwt_configure(&config)) // if the dwt_configure returns DWT_ERROR either the PLL or RX calibration has failed the host should reset the device
  {
    UART_puts("CONFIG FAILED\r\n");
    while (1)
      ;
  }

  /* Configure the TX spectrum parameters (power, PG delay and PG count) */
  dwt_configuretxrf(&txconfig_options);

  /* Apply default antenna delay value. See NOTE 2 below. */
  dwt_setrxantennadelay(RX_ANT_DLY);
  dwt_settxantennadelay(TX_ANT_DLY);

  /* Set expected response's delay and timeout. See NOTE 1 and 5 below.
   * As this example only handles one incoming frame with always the same delay and timeout, those values can be set here once for all. */
  dwt_setrxaftertxdelay(POLL_TX_TO_RESP_RX_DLY_UUS);
  dwt_setrxtimeout(RESP_RX_TIMEOUT_UUS);

  /* Next can enable TX/RX states output on GPIOs 5 and 6 to help debug, and also TX/RX LEDs
   * Note, in real low power applications the LEDs should not be used. */
  dwt_setlnapamode(DWT_LNA_ENABLE | DWT_PA_ENABLE);

  Serial.println("Range RX");
  Serial.println("Setup over........");

  btSerial.begin("Gatorball Tag");  //Bluetooth device name
  btSerial.connect();
  Serial.println("Bluetooth was set up");
}

void loop()
{
  if (!SerialBT.hasClient()) {
    SerialBT.begin("ESP32_Distance"); // Reconnect if disconnected
}
  /* Write frame data to DW IC and prepare transmission. See NOTE 7 below. */
  tx_poll_msg[ALL_MSG_SN_IDX] = frame_seq_nb;
  dwt_write32bitreg(SYS_STATUS_ID, SYS_STATUS_TXFRS_BIT_MASK);
  dwt_writetxdata(sizeof(tx_poll_msg), tx_poll_msg, 0); /* Zero offset in TX buffer. */
  dwt_writetxfctrl(sizeof(tx_poll_msg), 0, 1);          /* Zero offset in TX buffer, ranging. */

  /* Start transmission, indicating that a response is expected so that reception is enabled automatically after the frame is sent and the delay
   * set by dwt_setrxaftertxdelay() has elapsed. */
  dwt_starttx(DWT_START_TX_IMMEDIATE | DWT_RESPONSE_EXPECTED);

  /* We assume that the transmission is achieved correctly, poll for reception of a frame or error/timeout. See NOTE 8 below. */
  while (!((status_reg = dwt_read32bitreg(SYS_STATUS_ID)) & (SYS_STATUS_RXFCG_BIT_MASK | SYS_STATUS_ALL_RX_TO | SYS_STATUS_ALL_RX_ERR)))
  {
  };

  /* Increment frame sequence number after transmission of the poll message (modulo 256). */
  frame_seq_nb++;

  if (status_reg & SYS_STATUS_RXFCG_BIT_MASK)
  {
    uint32_t frame_len;

    /* Clear good RX frame event in the DW IC status register. */
    dwt_write32bitreg(SYS_STATUS_ID, SYS_STATUS_RXFCG_BIT_MASK);

    /* A frame has been received, read it into the local buffer. */
    frame_len = dwt_read32bitreg(RX_FINFO_ID) & RXFLEN_MASK;
    if (frame_len <= sizeof(rx_buffer))
    {
      dwt_readrxdata(rx_buffer, frame_len, 0);

      /* Check that the frame is the expected response from the companion "SS TWR responder" example.
       * As the sequence number field of the frame is not relevant, it is cleared to simplify the validation of the frame. */
      rx_buffer[ALL_MSG_SN_IDX] = 0;
      if (memcmp(rx_buffer, rx_resp_msg, ALL_MSG_COMMON_LEN) == 0)
      {
        uint32_t poll_tx_ts, resp_rx_ts, poll_rx_ts, resp_tx_ts;
        int32_t rtd_init, rtd_resp;
        float clockOffsetRatio;

        /* Retrieve poll transmission and response reception timestamps. See NOTE 9 below. */
        poll_tx_ts = dwt_readtxtimestamplo32();
        resp_rx_ts = dwt_readrxtimestamplo32();
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

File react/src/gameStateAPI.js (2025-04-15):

import express from "express";
import cors from "cors";
import fs from "fs";

const app = express();
app.use(cors());
app.use(express.json());
const PORT = process.env.PORT || 3002;

const FILE_PATH = "gameStates.json";
let gameStates = [];

fs.readFile(FILE_PATH, "utf-8", (err, data) => {
  if (!err && data) {
    try {
      gameStates = JSON.parse(data);
    } catch (parseError) {
      console.error("Error parsing existing game states: ", parseError);
      gameStates = []; // Reset to empty if there's a parsing issue
    }
  }
});

// Save game states to file
const saveStatesToFile = () => {
  fs.writeFile(FILE_PATH, JSON.stringify(gameStates, null, 2), (err) => {
    if (err) {
      console.error("Error saving game states: ", err);
    } else {
      console.log("Game states saved successfully!");
    }
  });
};

// Save game states periodically every 5 seconds
setInterval(saveStatesToFile, 5000);

// API endpoint to receive game states
app.post("/api/game-states", (req, res) => {
  const { gameStates: newStates } = req.body;

  if (!Array.isArray(newStates) || newStates.length === 0) {
    return res.status(400).json({ message: "Invalid game state data" });
  }

  gameStates.push(...newStates); // Append new states to in-memory storage
  res.status(201).json({ message: "Game states received!" });
});

// API endpoint to get all game states
app.get("/api/game-states", (req, res) => {
  res.json(gameStates);
});

app.listen(PORT, () => {
  console.log(`Game State server running on port ${PORT}`);
});

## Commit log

2024-10-08 Newest version of master timesheet. Recorded work time for meeting held on 10/8/2024.
    [CEN3907C Effort Log.xlsx]
2024-10-15 Added new times.
    [CEN3907C Effort Log.xlsx]
2024-10-22 Created frontend. TODO: fix positioning of elements as they are a little messed up upon updating, rework updating function
    [ui.py]
2024-10-24 Vendor examples to test boards
2024-11-20 Ball reflects distance of tag from anchor point (currently only one). Minor UI changes. TODO: Cosmetic improvements
2025-01-31 3D model files for beta testing
    [basic_pylon.FCStd, football.blend]
2025-03-27 Pylon design files
    [pylon_w_power.FCStd, pylon_w_power.stl]
2025-04-17 Final Demo Updates
    [position_log.csv]
